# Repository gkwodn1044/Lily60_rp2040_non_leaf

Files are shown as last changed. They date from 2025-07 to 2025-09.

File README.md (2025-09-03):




HJGing님의 KPRP 프로젝트중 [Lily60_rp2040](https://github.com/Keyboard-PCB-Replica-Project/Lily60_rp2040.git) repo를 fork하여 non leaf 버전으로 수정한 PCB입니다. 

GOK Lily 레플리카 PCB입니다.

추후에 인디케이터용 RGB LED나 SMD LED가 추가될 수도 있습니다.

(현재는 백색 2핀 LED와 오른쪽 아래 LED만 구현해 두었습니다.)

추가 필요 부품 : 

작동 확인 여부 : X

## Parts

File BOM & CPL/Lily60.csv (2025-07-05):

Reference | Footprint | Value | LCSC Part Number
BOOTSEL1 | XKB_TS-1187A | SW_Push | C318884
C1,C2,C3,C4,C5,C6,C7,C9,C10,C16,C17,C18,C19,C20 | C0402 | 100n | C1525
C8,C11,C12,C13 | C0402 | 1u | C52923
C14,C15 | C0402 | 15p | C1548
D1,D2,D3,D4,D5,D6,D7,D8,D9,D10,D11,D12,D13,D14,D15,D16,D17,D18,D19,D20,D21,D22,D23,D24,D25,D26,D27,D28,D29,D30,D31,D32,D33,D34,D35,D36,D37,D38,D39,D40,D41,D42,D43,D44,D45,D46,D47,D48,D49,D50,D51,D52,D53,D54,D55,D56,D57,D58,D59,D60,D61,D62 | SOD-123 | D_Small | C7420318
D63,D64,D66 | SK6812MINI-E | LED_SK6812MINI | C5149201
J2 | SM04B-SRSS-TB | Conn_01x04 | C160404
R1,R2 | C0603 | 27.4R | C25190
R3 | C0402 | 220R | C25091
R4,R6 | C0402 | 1K | C11702
R5 | C0402 | 10k | C25744
R7 | C0402 | 300R | C25102
U1 | QFN-56 | RP2040 | C2040
U2 | SOT-23 | XC6206PxxxMR | C5446
U3 | SOIC-8_5.23x5.23mm | W25Q128JVS | C97521
U4 | SOT-23-6 | SRV05-4 | C7420376
Y1 | XO32-4Pin_3.2x2.5mm | ABM8-272-T3 | C20625731

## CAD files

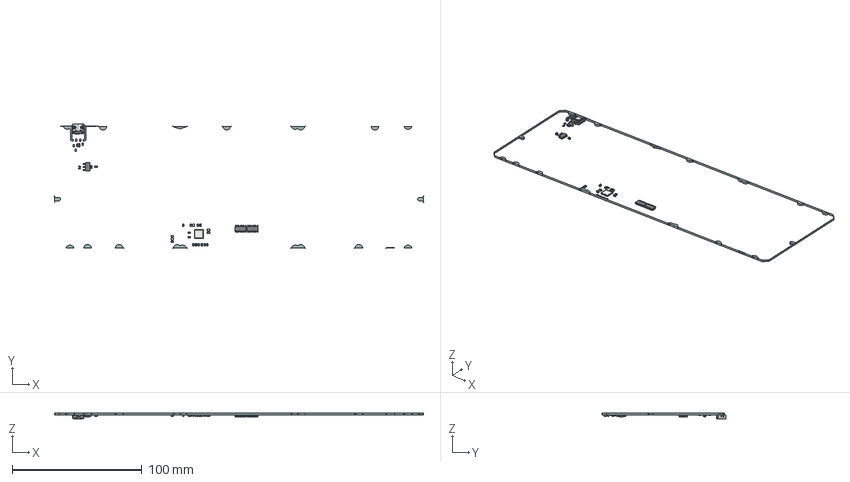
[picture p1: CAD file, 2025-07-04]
Lily60.step
284.3 x 95.7 x 4.96 mm
R_0805_2012Metric x 8
C_0805_2012Metric x 16
SOIC_14_39x87mm_P127mm x 2
QFN-56-1EP_7x7mm_Pitch0.4mm
SOT_23_6
SOT_223
Fuse_0805_2012Metric
USB_C_Receptacle_16P_TopMnt_Horizontal_GCT_USB4105-xx-A
63_4_PCB

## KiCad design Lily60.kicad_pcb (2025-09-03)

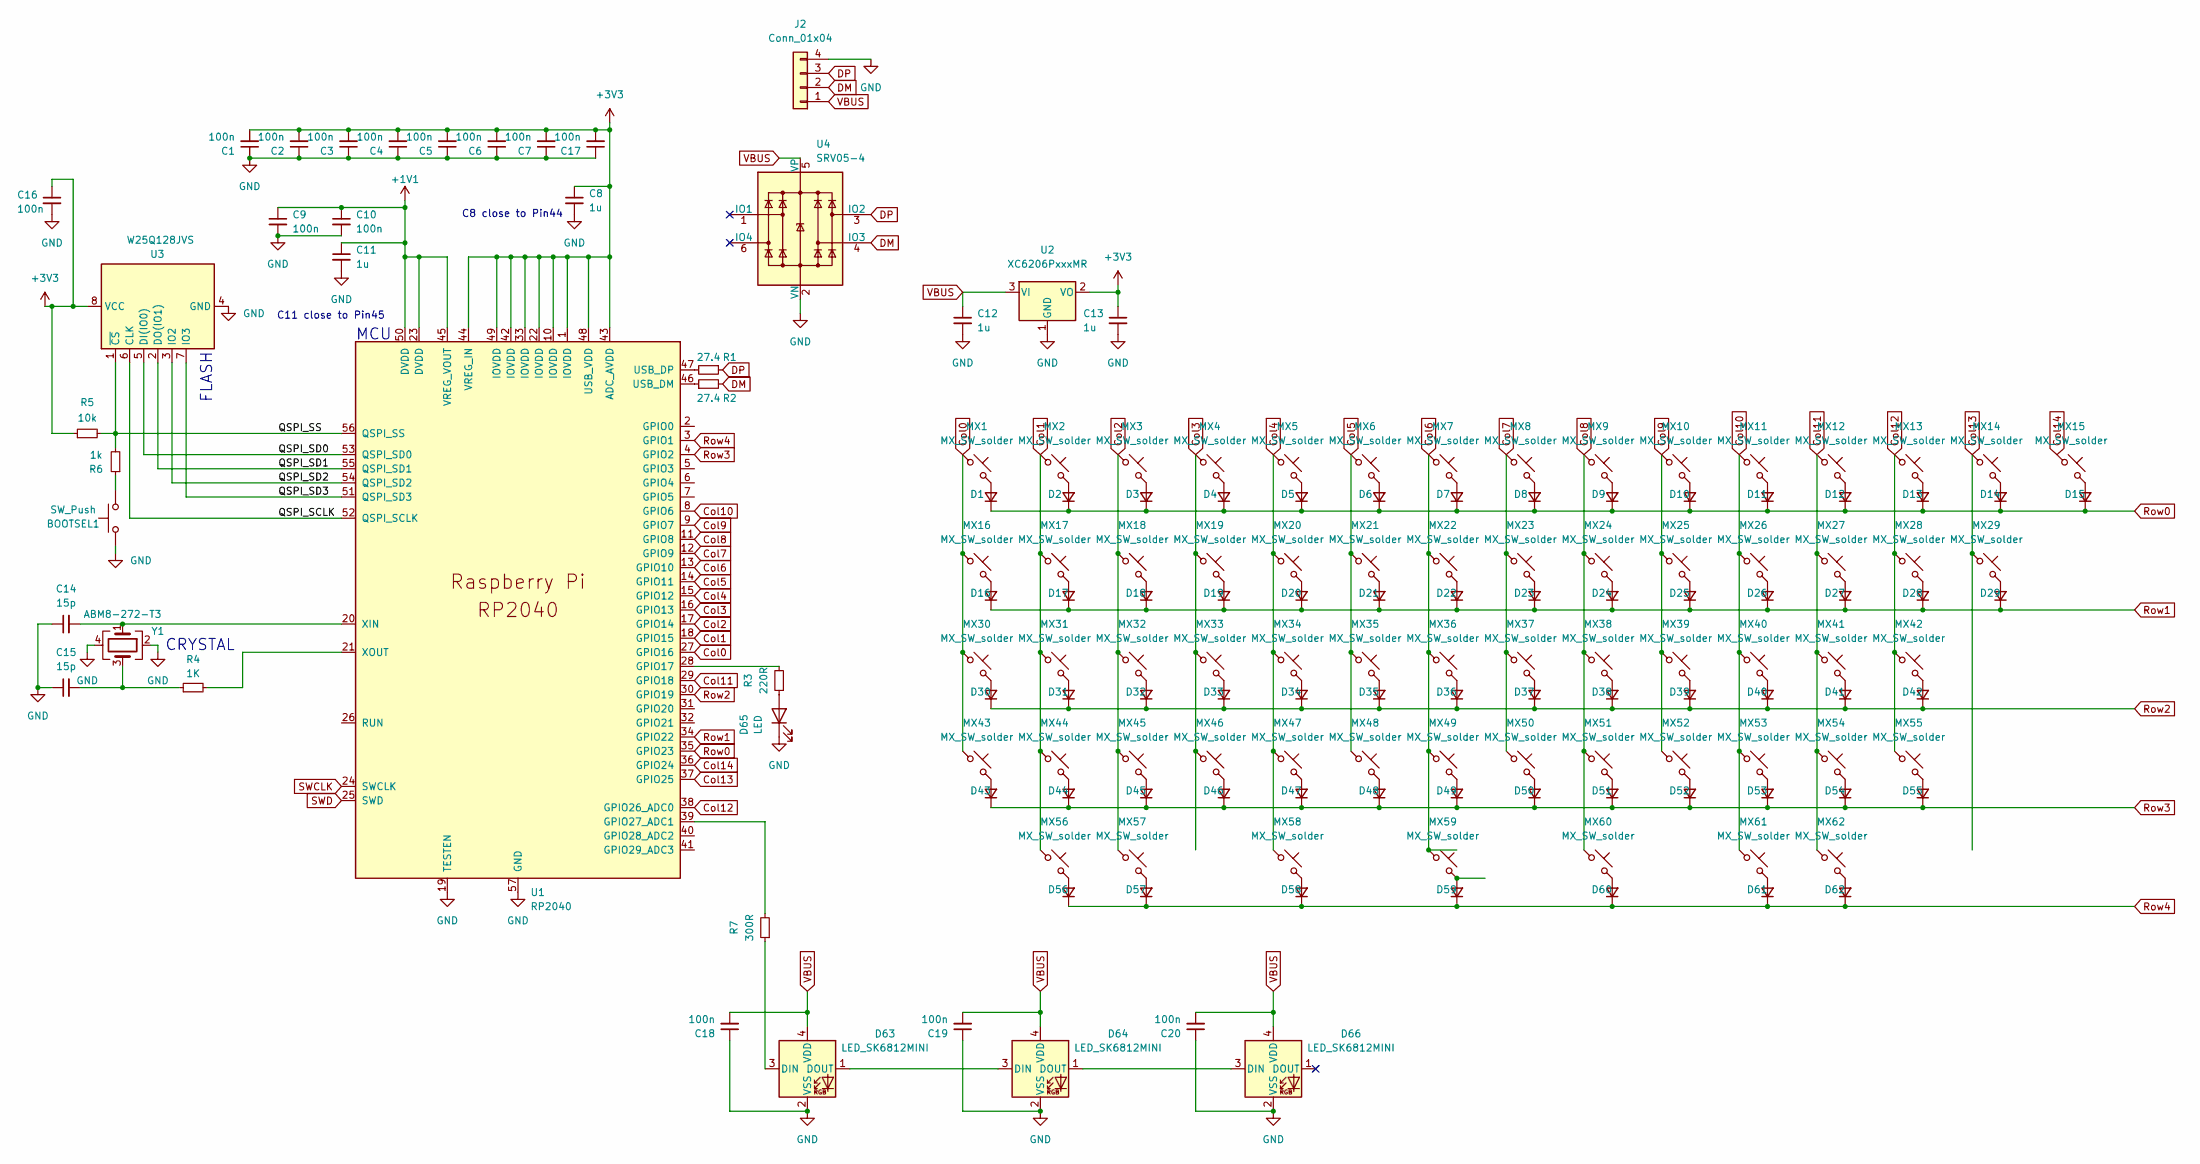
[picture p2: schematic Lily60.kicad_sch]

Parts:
BOOTSEL1: SW_Push; SW_Push_1P1T_XKB_TS-1187A
C1, C2, C3, C4, C5, C6, C7, C9, C10, C16, C17, C18, C19, C20: 100n; C_0402_1005Metric
C8, C11, C12, C13: 1u; C_0402_1005Metric
C14, C15: 15p; C_0402_1005Metric
D1, D2, D3, D4, D5, D6, D7, D8, D9, D10, D11, D12, D13, D14, D15, D16, D17, D18, D19, D20, D21, D22, D23, D24, D25, D26, D27, D28, D29, D30, D31, D32, D33, D34, D35, D36, D37, D38, D39, D40, D41, D42, D43, D44, D45, D46, D47, D48, D49, D50, D51, D52, D53, D54, D55, D56, D57, D58, D59, D60, D61, D62: D_Small; Diode_SOD-123_noref2
D63, D64, D66: LED_SK6812MINI; LED_SK6812MINI-E_clrce
D65: LED; cherry_ledhole
J2: Conn_01x04; JST_SH_SM04B-SRSS-TB_1x04-1MP_P1.00mm_Horizontal
MX1, MX2, MX3, MX4, MX5, MX6, MX7, MX8, MX9, MX10, MX11, MX12, MX13, MX14, MX15, MX16, MX17, MX18, MX19, MX20, MX21, MX22, MX23, MX24, MX25, MX26, MX27, MX28, MX29, MX30, MX31, MX32, MX33, MX34, MX35, MX36, MX37, MX38, MX39, MX40, MX41, MX42, MX43, MX44, MX45, MX46, MX47, MX48, MX49, MX50, MX51, MX52, MX53, MX54, MX55, MX56, MX57, MX58, MX59, MX60, MX61, MX62: MX_SW_solder; MX_PCB_1.00u_NoSilkscreen3
R1, R2: 27.4; C_0603_1608Metric
R3: 220R; C_0402_1005Metric_noref
R4: 1K; C_0402_1005Metric
R5: 10k; C_0402_1005Metric
R6: 1k; C_0402_1005Metric
R7: 300R; C_0402_1005Metric
U1: RP2040; RP2040-QFN-56
U2: XC6206PxxxMR; SOT-23
U3: W25Q128JVS; SOIC-8_5.23x5.23mm_P1.27mm
U4: SRV05-4; SOT-23-6
Y1: ABM8-272-T3; Oscillator_SMD_EuroQuartz_XO32-4Pin_3.2x2.5mm

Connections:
+1V1: C9.1, C10.1, C11.1, U1.23 (DVDD), U1.45 (VREG_VOUT), U1.50 (DVDD)
+3V3: C1.2, C2.2, C3.2, C4.2, C5.2, C6.2, C7.2, C8.1, C13.1, C16.1, C17.2, R5.1, U1.1 (IOVDD), U1.10 (IOVDD), U1.22 (IOVDD), U1.33 (IOVDD), U1.42 (IOVDD), U1.43 (ADC_AVDD), U1.44 (VREG_IN), U1.48 (USB_VDD), U1.49 (IOVDD), U2.2 (VO), U3.8 (VCC)
/QSPI_SCLK: U1.52 (QSPI_SCLK), U3.6 (CLK)
/QSPI_SD0: U1.53 (QSPI_SD0), U3.5 (DI(IO0))
/QSPI_SD1: U1.55 (QSPI_SD1), U3.2 (DO(IO1))
/QSPI_SD2: U1.54 (QSPI_SD2), U3.3 (IO2)
/QSPI_SD3: U1.51 (QSPI_SD3), U3.7 (IO3)
/QSPI_SS: R5.2, R6.2, U1.56 (QSPI_SS), U3.1 (~CS)
Col0: MX1.1, MX16.1, MX30.1, MX43.1, U1.27 (GPIO16)
Col1: MX2.1, MX17.1, MX31.1, MX44.1, MX56.1, U1.18 (GPIO15)
Col2: MX3.1, MX18.1, MX32.1, MX45.1, MX57.1, U1.17 (GPIO14)
Col3: MX4.1, MX19.1, MX33.1, MX46.1, U1.16 (GPIO13)
Col4: MX5.1, MX20.1, MX34.1, MX47.1, MX58.1, U1.15 (GPIO12)
Col5: MX6.1, MX21.1, MX35.1, MX48.1, U1.14 (GPIO11)
Col6: MX7.1, MX22.1, MX36.1, MX49.1, MX59.1, U1.13 (GPIO10)
Col7: MX8.1, MX23.1, MX37.1, MX50.1, U1.12 (GPIO9)
Col8: MX9.1, MX24.1, MX38.1, MX51.1, MX60.1, U1.11 (GPIO8)
Col9: MX10.1, MX25.1, MX39.1, MX52.1, U1.9 (GPIO7)
Col10: MX11.1, MX26.1, MX40.1, MX53.1, MX61.1, U1.8 (GPIO6)
Col11: MX12.1, MX27.1, MX41.1, MX54.1, MX62.1, U1.29 (GPIO18)
Col12: MX13.1, MX28.1, MX42.1, MX55.1, U1.38 (GPIO26_ADC0)
Col13: MX14.1, MX29.1, U1.37 (GPIO25)
Col14: MX15.1, U1.36 (GPIO24)
DM: J2.2, R2.2, U4.4 (IO3)
DP: J2.3, R1.1, U4.3 (IO2)
GND: BOOTSEL1.1, C1.1, C2.1, C3.1, C4.1, C5.1, C6.1, C7.1, C8.2, C9.2, C10.2, C11.2, C12.2, C13.2, C14.1, C15.1, C16.2, C17.1, C18.1, C19.1, C20.1, D63.2 (VSS), D64.2 (VSS), D65.1 (K), D66.2 (VSS), J2.4, U1.19 (TESTEN), U1.57 (GND), U2.1 (GND), U3.4 (GND), U4.2 (VN), Y1.2, Y1.4
unnamed: BOOTSEL1.2, R6.1
unnamed: C15.2, R4.1, Y1.3
unnamed: D1.2 (A), MX1.2
unnamed: D2.2 (A), MX2.2
unnamed: D3.2 (A), MX3.2
unnamed: D4.2 (A), MX4.2
unnamed: D5.2 (A), MX5.2
unnamed: D6.2 (A), MX6.2
unnamed: D7.2 (A), MX7.2
unnamed: D8.2 (A), MX8.2
unnamed: D9.2 (A), MX9.2
unnamed: D10.2 (A), MX10.2
unnamed: D11.2 (A), MX11.2
unnamed: D12.2 (A), MX12.2
unnamed: D13.2 (A), MX13.2
unnamed: D14.2 (A), MX14.2
unnamed: D15.2 (A), MX15.2
unnamed: D16.2 (A), MX16.2
unnamed: D17.2 (A), MX17.2
unnamed: D18.2 (A), MX18.2
unnamed: D19.2 (A), MX19.2
unnamed: D20.2 (A), MX20.2
unnamed: D21.2 (A), MX21.2
unnamed: D22.2 (A), MX22.2
unnamed: D23.2 (A), MX23.2
unnamed: D24.2 (A), MX24.2
unnamed: D25.2 (A), MX25.2
unnamed: D26.2 (A), MX26.2
unnamed: D27.2 (A), MX27.2
unnamed: D28.2 (A), MX28.2
unnamed: D29.2 (A), MX29.2
unnamed: D30.2 (A), MX30.2
unnamed: D31.2 (A), MX31.2
unnamed: D32.2 (A), MX32.2
unnamed: D33.2 (A), MX33.2
unnamed: D34.2 (A), MX34.2
unnamed: D35.2 (A), MX35.2
unnamed: D36.2 (A), MX36.2
unnamed: D37.2 (A), MX37.2
unnamed: D38.2 (A), MX38.2
unnamed: D39.2 (A), MX39.2
unnamed: D40.2 (A), MX40.2
unnamed: D41.2 (A), MX41.2
unnamed: D42.2 (A), MX42.2
unnamed: D43.2 (A), MX43.2
unnamed: D44.2 (A), MX44.2
unnamed: D45.2 (A), MX45.2
unnamed: D46.2 (A), MX46.2
unnamed: D47.2 (A), MX47.2
unnamed: D48.2 (A), MX48.2
unnamed: D49.2 (A), MX49.2
unnamed: D50.2 (A), MX50.2
unnamed: D51.2 (A), MX51.2
unnamed: D52.2 (A), MX52.2
unnamed: D53.2 (A), MX53.2
unnamed: D54.2 (A), MX54.2
unnamed: D55.2 (A), MX55.2
unnamed: D56.2 (A), MX56.2
unnamed: D57.2 (A), MX57.2
unnamed: D58.2 (A), MX58.2
unnamed: D59.2 (A), MX59.2
unnamed: D60.2 (A), MX60.2
unnamed: D61.2 (A), MX61.2
unnamed: D62.2 (A), MX62.2
unnamed: D63.3 (DIN), R7.1
unnamed: D63.1 (DOUT), D64.3 (DIN)
unnamed: D64.1 (DOUT), D66.3 (DIN)
unnamed: D65.2 (A), R3.1
unnamed: R3.2, U1.28 (GPIO17)
unnamed: R7.2, U1.39 (GPIO27_ADC1)
unnamed: R2.1, U1.46 (USB_DM)
unnamed: R1.2, U1.47 (USB_DP)
unnamed: C14.2, U1.20 (XIN), Y1.1
unnamed: R4.2, U1.21 (XOUT)
Row0: D1.1 (K), D2.1 (K), D3.1 (K), D4.1 (K), D5.1 (K), D6.1 (K), D7.1 (K), D8.1 (K), D9.1 (K), D10.1 (K), D11.1 (K), D12.1 (K), D13.1 (K), D14.1 (K), D15.1 (K), U1.35 (GPIO23)
Row1: D16.1 (K), D17.1 (K), D18.1 (K), D19.1 (K), D20.1 (K), D21.1 (K), D22.1 (K), D23.1 (K), D24.1 (K), D25.1 (K), D26.1 (K), D27.1 (K), D28.1 (K), D29.1 (K), U1.34 (GPIO22)
Row2: D30.1 (K), D31.1 (K), D32.1 (K), D33.1 (K), D34.1 (K), D35.1 (K), D36.1 (K), D37.1 (K), D38.1 (K), D39.1 (K), D40.1 (K), D41.1 (K), D42.1 (K), U1.30 (GPIO19)
Row3: D43.1 (K), D44.1 (K), D45.1 (K), D46.1 (K), D47.1 (K), D48.1 (K), D49.1 (K), D50.1 (K), D51.1 (K), D52.1 (K), D53.1 (K), D54.1 (K), D55.1 (K), U1.4 (GPIO2)
Row4: D56.1 (K), D57.1 (K), D58.1 (K), D59.1 (K), D60.1 (K), D61.1 (K), D62.1 (K), U1.3 (GPIO1)
SWCLK: U1.24 (SWCLK)
SWD: U1.25 (SWD)
VBUS: C12.1, C18.2, C19.2, C20.2, D63.4 (VDD), D64.4 (VDD), D66.4 (VDD), J2.1, U2.3 (VI), U4.5 (VP)

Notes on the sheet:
C11 close to Pin45
MCU
CRYSTAL
C8 close to Pin44
FLASH

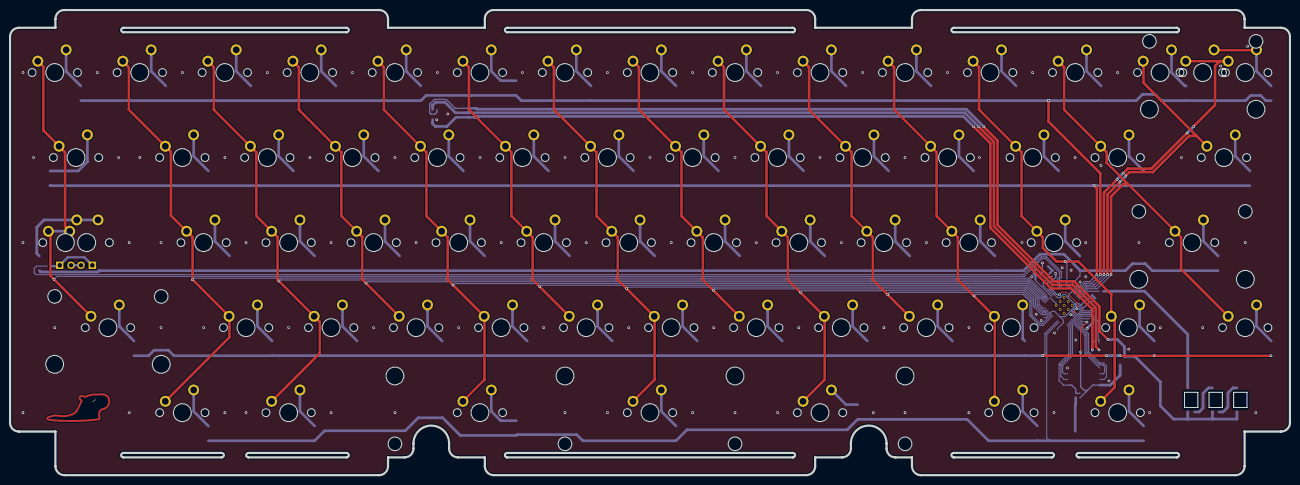
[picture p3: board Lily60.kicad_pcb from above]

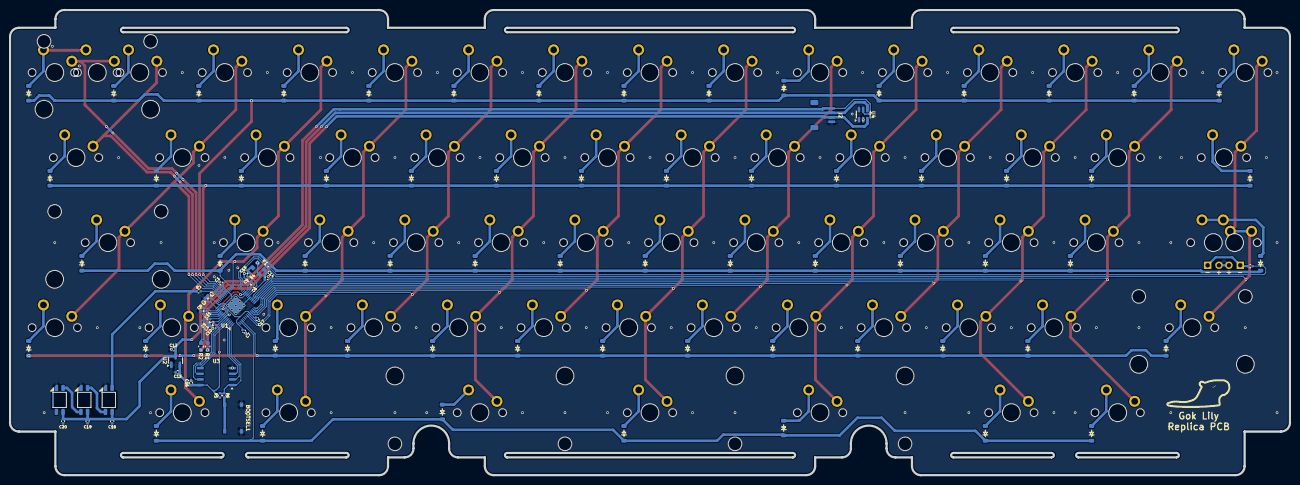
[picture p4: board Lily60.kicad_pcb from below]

Board: 2 copper layers, 286.8 x 104.2 mm, 162 parts (96 on the bottom side), 106 nets.

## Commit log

2025-09-03 change the PCB shape to non leaf version
    [Lily60.kicad_pcb]
2025-09-03 new gerber file is plotted. original one is gerber.zip.bak
    [Lily60-B_Cu.gbr, Lily60-B_Mask.gbr, Lily60-B_Paste.gbr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]
